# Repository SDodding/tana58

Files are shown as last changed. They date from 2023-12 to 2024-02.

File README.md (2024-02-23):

# Tana58

Handwired 58 key wireless split keyboard powered by ZMK

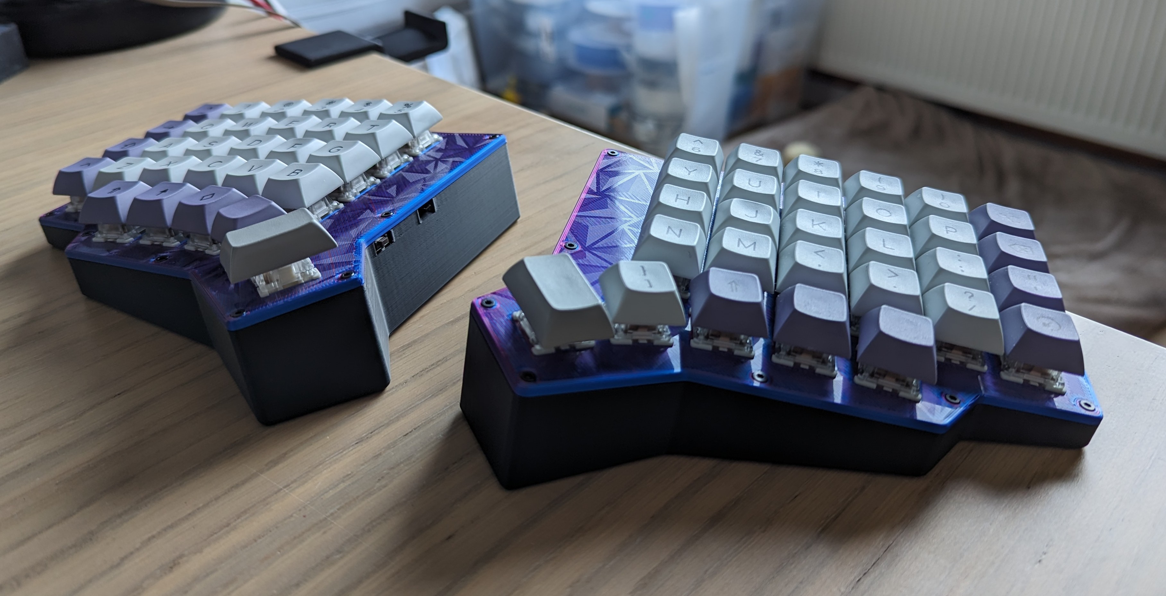
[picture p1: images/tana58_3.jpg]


Interesting files:

- What passes for a wiring diagram in /images
- STL files for 3d printing in /stls (There's only the left side, so you'll want to print a mirrored set)
- Freecad files if you wish to modify this for yourself, or for use with other components

Firmware for this board can be found [here](https://github.com/SDodding/tana58_zmk/tree/main)

BOM:

1. 2x Nice!Nano controllers or compatible. I used some Supermini NRF52840 Nice!Nano compatibles from aliexpress. I have since replaced them with proper Nice!Nanos however for better battery life and purchased them from [splitkb.com](https://splitkb.com/products/nice-nano).
2. 2x Mill Max low profile sockets (Mill Max 315-43-112-41-003000) with pins (Mill Max 3320-0-00-15-00-00-03-0). I used [these](https://splitkb.com/products/mill-max-low-profile-sockets?variant=31945995845709) from splitkb.com
3. 2x PCB grid boards that you don't mind chopping to size and drilling a hole through to mount on the controller bracket. I used some like [this](https://www.amazon.nl/-/en/gp/product/B07V39NT2Z) from Amazon and scored them carefully with a stanely knife before breaking them.
4. 58x MX Switches
5. 58x MX Keycaps. I used DSA caps from [spkeyboards.com](https://spkeyboards.com/pages/dsa-profile)
6. 58x THT signal diodes. I used [these](https://splitkb.com/products/tht-diodes) from splitkb.com (1N4148 Signal Diode)
7. 2x Reset switches. I used [these](https://splitkb.com/products/reset-buttons) from splitkb.com (SKHLLCA010). These were glued in to the support bracket in the model
8. 2x power switches.  
 I repurposed some three position ON-OFF-ON (SS 25539 N) switches for this from [Reichelt](https://www.reichelt.nl/nl/en/slide-switch-angled-pitch-5-08-1-x-on-off-on-ss-25539-n-p105722.html). The 3d model is set such that the second on position is physically blocked so that it acts only as a two position switch. You could follow this part, or update the bracket it's glued into in the freecad model for whatever you'd rather use.
9. 22x M2 threaded heat set inserts
10. 22x M2x8 screws
11. 2x 3.7v Lithium Polymer batteries with JST connector. I used some small 150mah ones from [Kiwi Electronics](https://www.kiwi-electronics.com/en/lithium-polymer-li-po-battery-3-7v-150mah-3459). I would say that there is a lot of room in the keyboard though due to the tenting, so you could easily fit 1200mah batteries (or larger) inside.
12. 2x Male JST-PH2.0 connectors. Do ensure the wire colours match the battery connectors before using any you buy. I bought some off Amazon and the connectors originally connected red to black and black to red...

Of course ALWAYS check the battery with a multimeter before connecting it to ensure the polarity is as expected.

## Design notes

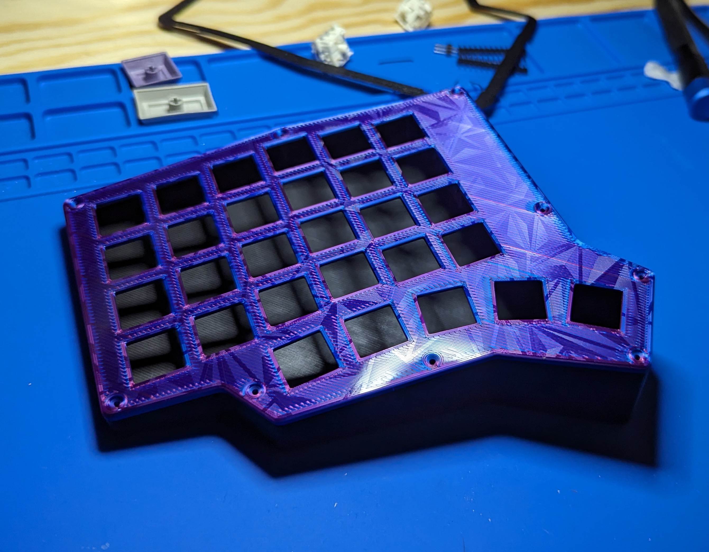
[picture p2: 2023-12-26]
images/tana58_case.jpg

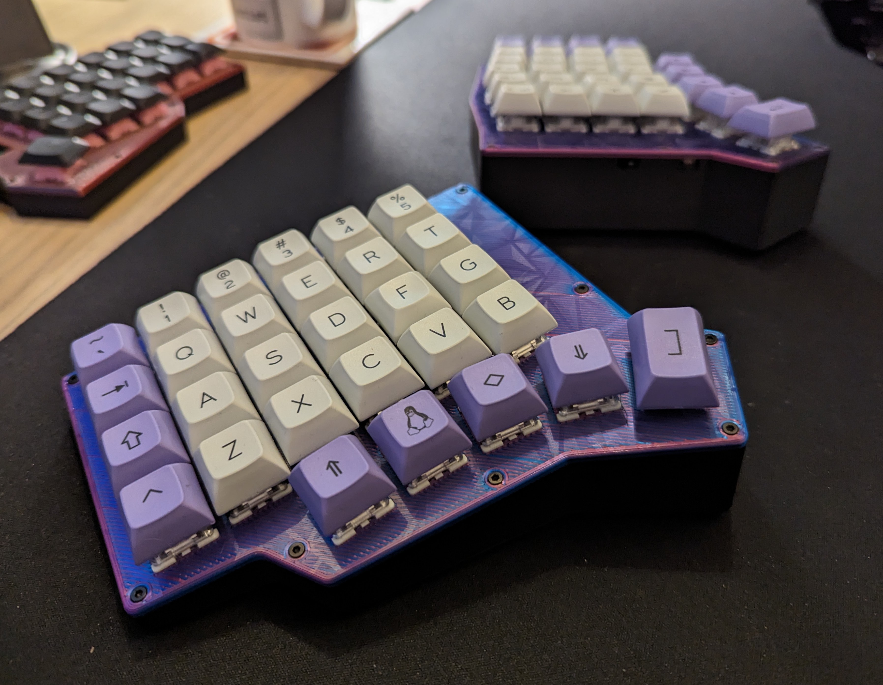
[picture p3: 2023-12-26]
images/tana58_2.jpg

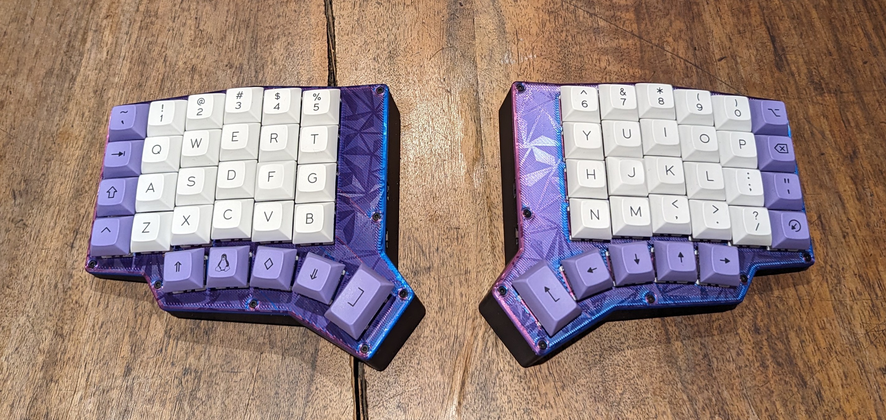
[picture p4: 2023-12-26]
images/tana58_1.jpg

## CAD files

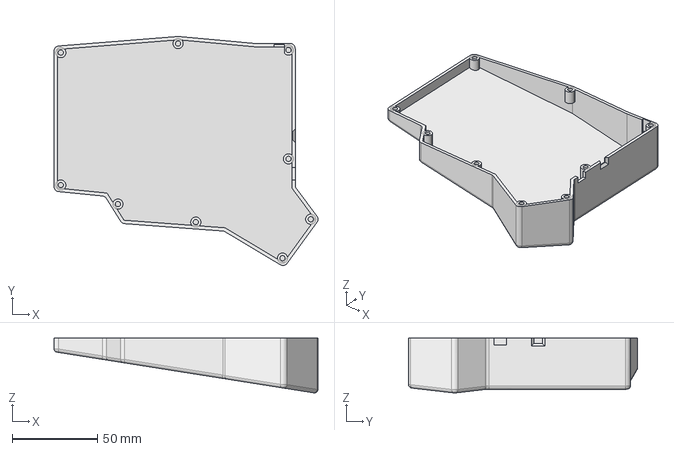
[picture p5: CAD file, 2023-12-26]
freecad/tana58_bottom_dressed.FCStd
155.3 x 134.7 x 32.2 mm

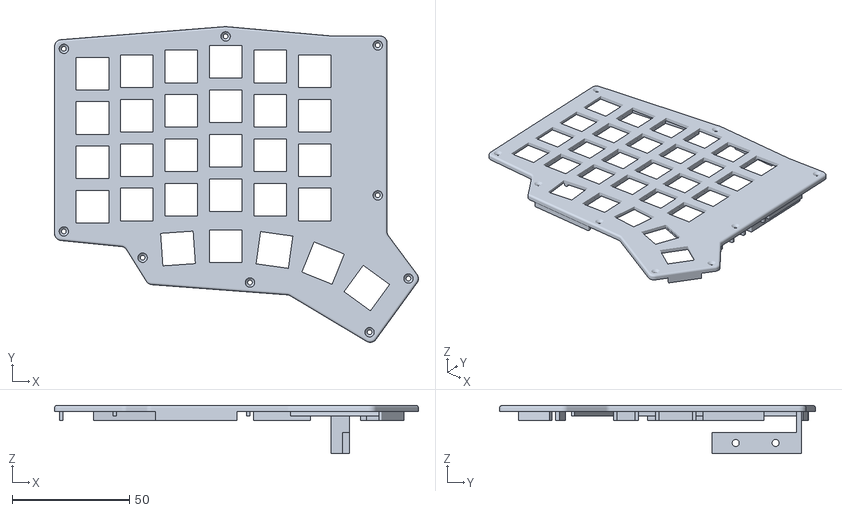
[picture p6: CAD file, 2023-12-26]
stls/tana58_top_dressed-Body.stl
155.3 x 134.7 x 20.5

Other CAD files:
freecad/tana58_dressed.FCStd
stls/tana58_bottom_dressed-Body.stl

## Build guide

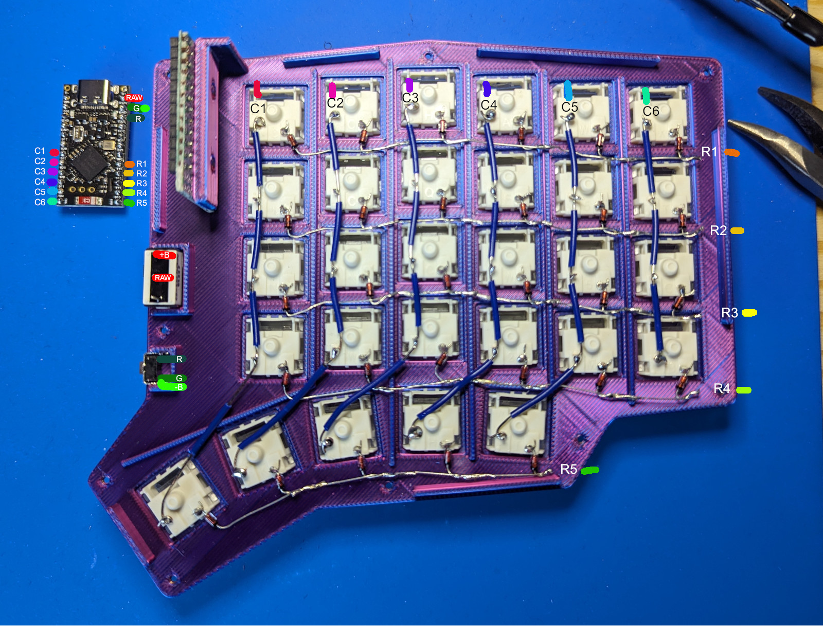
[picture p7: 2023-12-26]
images/tana58_wiring.jpg

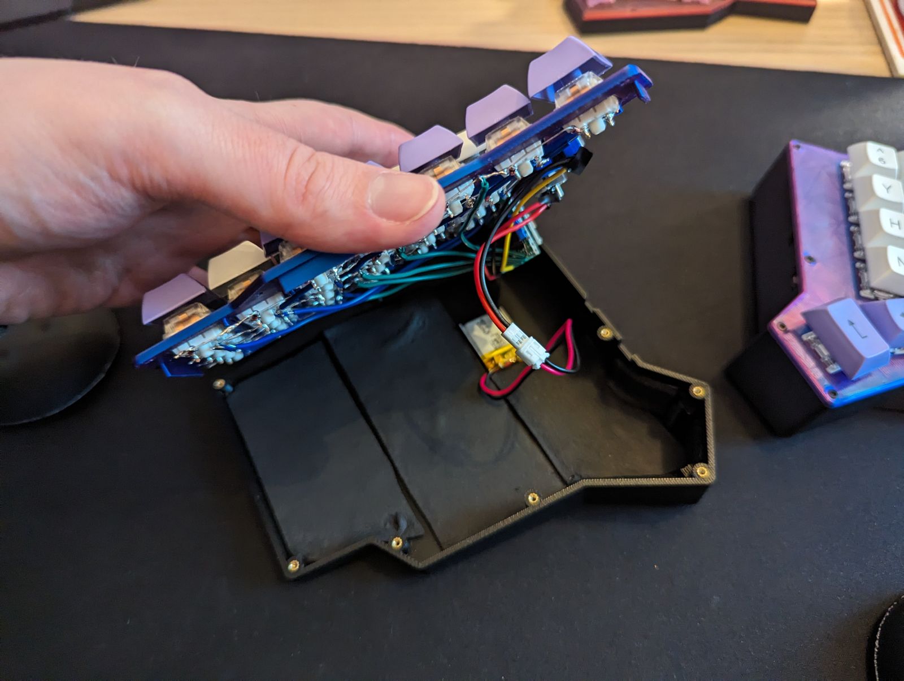
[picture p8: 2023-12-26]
images/tana58_wiring_with_batt.jpg

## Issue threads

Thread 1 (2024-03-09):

Can I make a wired version of this?

impopular-guy, 2024-03-09:
Hi
I would love to make a wired version of this, but I am very new to this. I would like to know:

1. if the case is compatible with other microcontrollers?
2. if will it be possible to make holes and other support for TRRS and all that?

SDodding, 2024-03-10:
Hey there!

1. The case has a slightly odd way of mounting the controller vertically and relies on you cutting and drilling a PCB grid board to solder the controller socket to (see attached). There is plenty of space inside for anything from something with a pro-micro footprint to a raspberry pi if you wanted - though different controller shapes may require moving the USB cutout.

The short answer though is that anything with a pro micro footprint will fit and line up with the USB hole with no additional work assuming you use Mill Max low profile sockets like the ones from the readme.

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

2. The Freecad source files are included here, so potentially you could modify the side ports yourself (replace the power switch location with a TRRS slot perhaps?) - that's the only thing stopping it from being used wired. Firmware wise it'll work with a slightly modified Lily58 QMK/KMK firmware.

I am planning on pushing a bunch of updates to this design soon now that I've been using it for a few months - I'll look at including a version of the top/bottom plates that accommodates a TRRS port, and perhaps a simpler controller mounting system.

This one might be a confusing initial build to start with though as it's missing a proper build log. [This build guide](https://sanderg.nl/en/posts/how-to-split-keyboard-with-rp2040-and-kmk/) really helped me with my first keyboard (also using KMK) that ultimately led to me designing this one as a wireless board.
